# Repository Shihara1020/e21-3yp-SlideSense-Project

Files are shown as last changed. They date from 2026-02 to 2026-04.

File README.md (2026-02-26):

<p align="center">
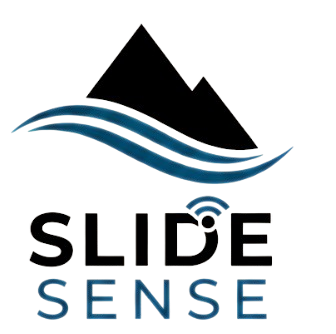
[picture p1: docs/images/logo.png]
  
</p>

<p align="center">
  
</p>

<p align="center">
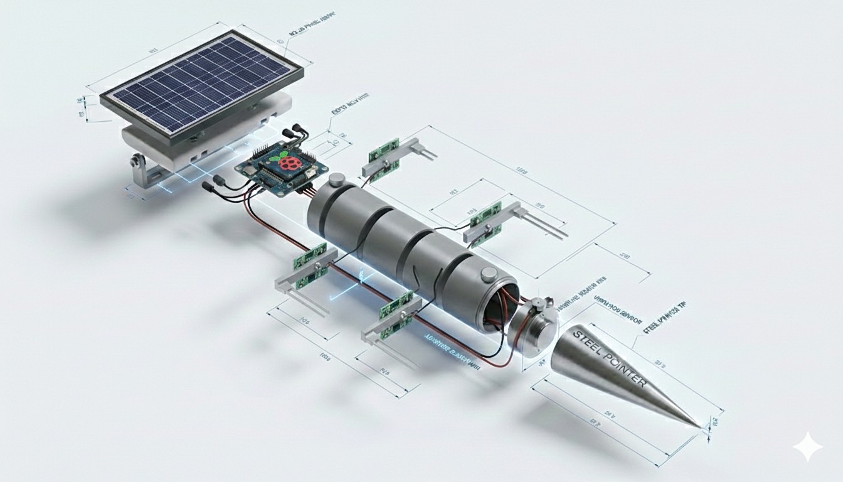
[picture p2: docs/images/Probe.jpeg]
  
</p>






## Team
- E/21/087, Shihara Dewagedara, [e21087@eng.pdn.ac.lk](mailto:e21087@eng.pdn.ac.lk)
- E/21/138, Fikry M.N.M., [e21138@eng.pdn.ac.lk](mailto:e21138@eng.pdn.ac.lk)
- E/21/302, Sahandi Perera, [e21302@eng.pdn.ac.lk](mailto:e21302@eng.pdn.ac.lk)
- E/21/452, Zaid M.R.M., [e21452@eng.pdn.ac.lk](mailto:e21452@eng.pdn.ac.lk)

#### Table of Contents

1. [Introduction](#introduction)
2. [Overall System Architecture](#overall-system-architecture)
3. [Data Flow Architecture](#data-flow-architecture)
4. [Software Architecture & Stack](#software-architecture--stack)
5. [Project Timeline](#project-timeline)
6. [Detailed Budget](#detailed-budget)
7. [Conclusion & Future Work](#conclusion--future-work)
8. [Links](#links)

## Introduction

Landslides remain a significant threat in hilly regions of Sri Lanka, often triggered by intense monsoon rainfall. **SlideSense** is an integrated IoT solution designed for real-time monitoring of high-risk slopes. 

The system moves beyond simple data logging by incorporating:
- **Redundant Communication:** Utilizing both Cloud (AWS/Firebase) and Local (Gateway) paths.
- **Edge Intelligence:** Real-time threshold analysis on the ESP32 to trigger immediate local sirens.
- **Resilience:** Designed to function even when external cellular networks fail during heavy storms.

## Overall System Architecture

SlideSense follows a **multi-layer IoT architecture**:

- **Perception Layer:** Distributed sensor nodes (ESP32) collect soil moisture, volumetric water content, and tilt data.
- **Network Layer:** Data is transmitted via MQTT protocol to a central Raspberry Pi gateway and subsequently to the AWS IoT Core.
- **Application Layer:** A React-based web dashboard and Firebase Cloud Messaging (FCM) provide localized alerts and historical data visualization for authorities.

## Data Flow Architecture

The system ensures reliable and redundant data transmission:

1. Sensors collect environmental data  
2. ESP32 performs edge analysis  
3. Data transmitted via LoRa / SIM900A  
4. Cloud (AWS/Firebase) processes & stores data  
5. Alerts triggered via Dashboard / SMS / FCM  

<p align="center">
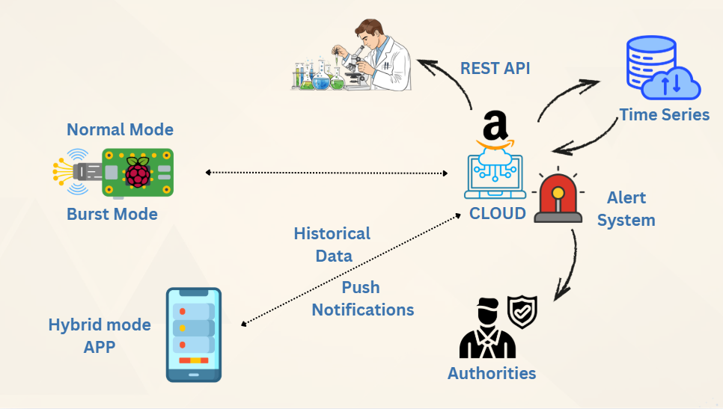
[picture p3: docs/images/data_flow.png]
  
</p>

##  Core Components

- **ESP32 WROOM 32U**
- **Capacitive Soil Moisture Sensors (x4)**
- **Tipping Bucket Rain Gauge**
- **High Sensitivity Microphone Sensor**
- **LoRa RA-02 SX1278 Module**
- **SIM900A GSM Module**
- **20W Solar Panel**
- **MPPT Charge Controller**
- **3.7V Li-Po Battery**

## ⚡ Power System

- MPPT Solar Charging
- 3.3V Regulation
- Deep Sleep Power Optimization

## Software Architecture & Stack

## 🧠 Firmware
- Arduino Framework
- FreeRTOS Task Management
- MQTT Communication
- Deep Sleep Mode

## ☁️ Backend & Cloud
- AWS IoT Core / Firebase
- Mosquitto MQTT Broker
- Node.js Gateway (Optional)
- Firebase Cloud Messaging (Alerts)

## 🖥 Frontend
- React.js Dashboard
- Real-time Data Visualization
- Alert Monitoring Panel

## 🛠 Software Stack Diagram

<p align="center">
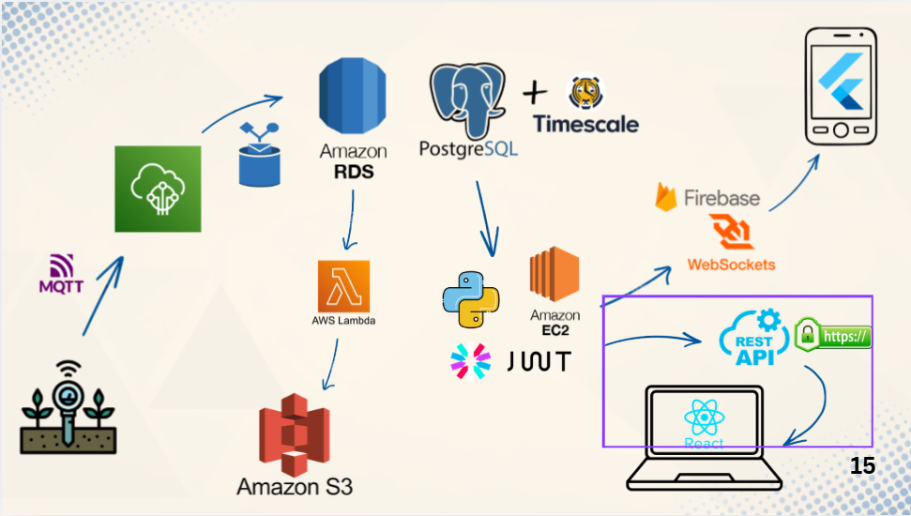
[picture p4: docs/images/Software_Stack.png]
  
</p>

##  Project Timeline

The project was executed in four structured milestones:

- Milestone 01 – Proposal & Planning  
- Milestone 02 – Hardware Setup & Testing  
- Milestone 03 – Working Prototype  
- Milestone 04 – Final Product & Documentation  

<p align="center">
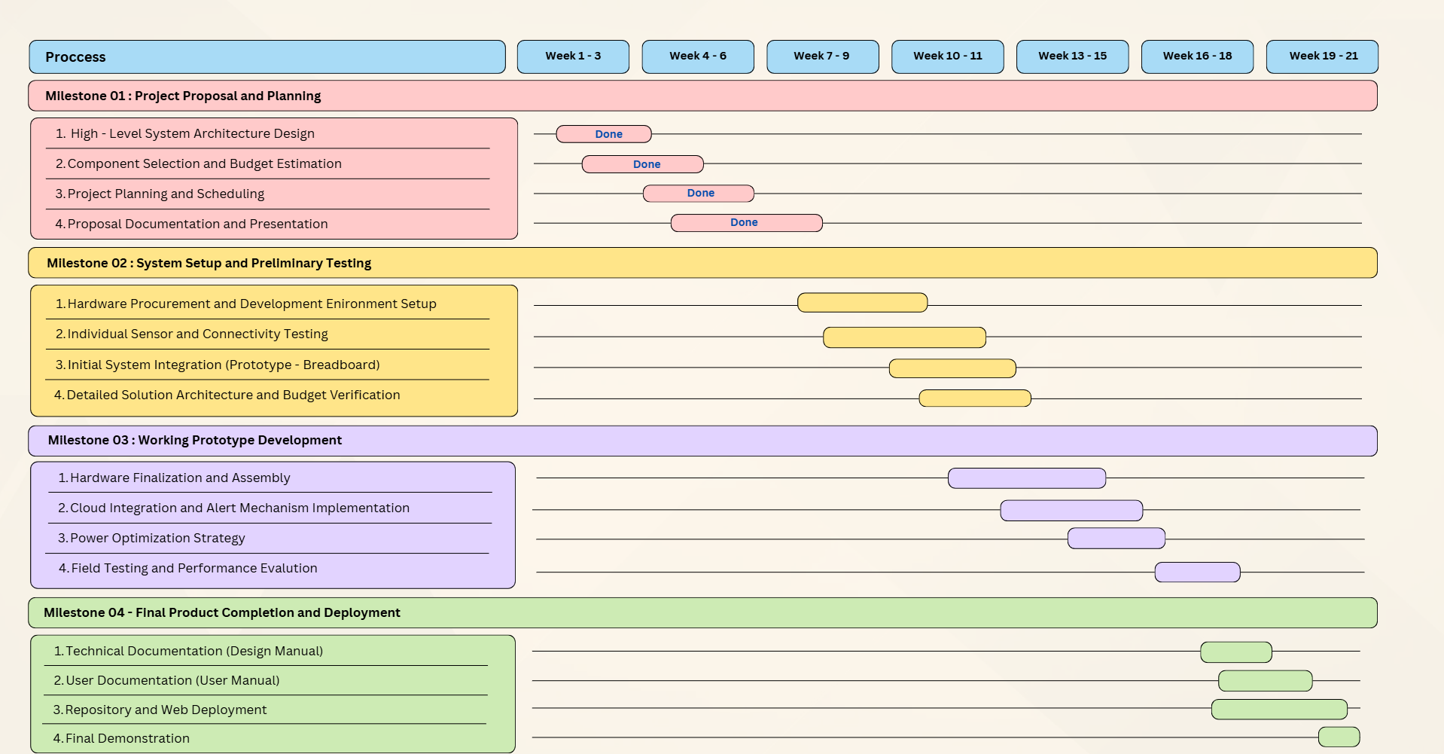
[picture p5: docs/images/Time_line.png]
  
</p>

## Detailed Budget

| Item | Quantity | Unit Cost (LKR) | Total (LKR) |
| :--- | :---: | :---: | :---: |
| 20W Solar Panel | 1 | 3,350 | 3,350 |
| Li-Po Battery | 1 | 1,185 | 1,185 |
| MPPT Controller | 1 | 1,450 | 1,450 |
| Voltage Regulator | 1 | 120 | 120 |
| ESP32 | 1 | 1,860 | 1,860 |
| Soil Moisture Sensor | 4 | 290 | 1,160 |
| Tipping Bucket | 1 | 4,000 | 4,000 |
| LoRa Module | 1 | 1,500 | 1,500 |
| Microphone Sensor | 1 | 200 | 200 |
| SIM900A | 1 | 1,450 | 1,450 |
| **Total Cost** |  |  | **16,275 LKR** |

## Conclusion & Future Work

SlideSense demonstrates a **cost-effective, scalable, and resilient landslide monitoring system** integrating edge intelligence with cloud-based alerts.

### Future Enhancements
- LoRaWAN integration for extended mountainous coverage  
- Machine Learning (LSTM-based rainfall prediction)  
- IP67-rated rugged enclosure  
- Mobile application for public warning

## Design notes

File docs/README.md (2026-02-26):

---
layout: home
permalink: index.html
repository-name: e21-3yp-SlideSense
title: SlideSense
---

<p align="center">
  
</p>

<p align="center">
  
</p>

<p align="center">
  
</p>

## Team
- E/21/087, Shihara Dewagedara, [e21087@eng.pdn.ac.lk](mailto:e21087@eng.pdn.ac.lk)
- E/21/138, Fikry M.N.M., [e21138@eng.pdn.ac.lk](mailto:e21138@eng.pdn.ac.lk)
- E/21/302, Sahandi Perera, [e21302@eng.pdn.ac.lk](mailto:e21302@eng.pdn.ac.lk)
- E/21/452, Zaid M.R.M., [e21452@eng.pdn.ac.lk](mailto:e21452@eng.pdn.ac.lk)

#### Table of Contents

1. [Introduction](#introduction)
2. [Overall System Architecture](#overall-system-architecture)
3. [Data Flow Architecture](#data-flow-architecture)
4. [Hardware Design](#hardware-design)
5. [Software Architecture & Stack](#software-architecture--stack)
6. [Project Timeline](#project-timeline)
7. [Testing & Validation](#testing--validation)
8. [Detailed Budget](#detailed-budget)
9. [Conclusion & Future Work](#conclusion--future-work)
10. [Links](#links)

## Introduction

Landslides remain a significant threat in hilly regions of Sri Lanka, often triggered by intense monsoon rainfall. **SlideSense** is an integrated IoT solution designed for real-time monitoring of high-risk slopes. 

The system moves beyond simple data logging by incorporating:
- **Redundant Communication:** Utilizing both Cloud (AWS/Firebase) and Local (Gateway) paths.
- **Edge Intelligence:** Real-time threshold analysis on the ESP32 to trigger immediate local sirens.
- **Resilience:** Designed to function even when external cellular networks fail during heavy storms.

## Overall System Architecture

SlideSense follows a **multi-layer IoT architecture**:

- **Perception Layer:** Distributed sensor nodes (ESP32) collect soil moisture, volumetric water content, and tilt data.
- **Network Layer:** Data is transmitted via MQTT protocol to a central Raspberry Pi gateway and subsequently to the AWS IoT Core.
- **Application Layer:** A React-based web dashboard and Firebase Cloud Messaging (FCM) provide localized alerts and historical data visualization for authorities.

<p align="center">
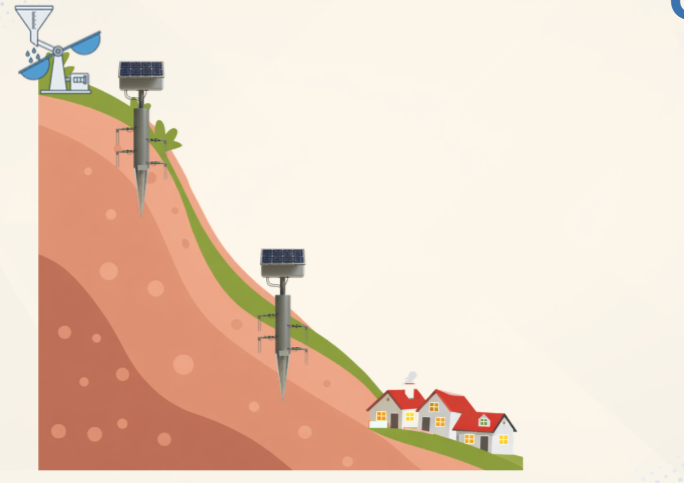
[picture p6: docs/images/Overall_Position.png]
  
</p>

## Data Flow Architecture

The system ensures reliable and redundant data transmission:

1. Sensors collect environmental data  
2. ESP32 performs edge analysis  
3. Data transmitted via LoRa / SIM900A  
4. Cloud (AWS/Firebase) processes & stores data  
5. Alerts triggered via Dashboard / SMS / FCM  

<p align="center">
  
</p>

##  Core Components

- **ESP32 WROOM 32U**
- **Capacitive Soil Moisture Sensors (x4)**
- **Tipping Bucket Rain Gauge**
- **High Sensitivity Microphone Sensor**
- **LoRa RA-02 SX1278 Module**
- **SIM900A GSM Module**
- **20W Solar Panel**
- **MPPT Charge Controller**
- **3.7V Li-Po Battery**

##  Power System

- MPPT Solar Charging
- 3.3V Regulation
- Deep Sleep Power Optimization

## Software Architecture & Stack

## Firmware
- Arduino Framework
- FreeRTOS Task Management
- MQTT Communication
- Deep Sleep Mode

##  Backend & Cloud
- AWS IoT Core / Firebase
- Mosquitto MQTT Broker
- Node.js Gateway (Optional)
- Firebase Cloud Messaging (Alerts)

##  Frontend
- React.js Dashboard
- Real-time Data Visualization
- Alert Monitoring Panel

## 🛠 Software Stack Diagram

<p align="center">
  
</p>

##  Project Timeline

The project was executed in four structured milestones:

- Milestone 01 – Proposal & Planning  
- Milestone 02 – Hardware Setup & Testing  
- Milestone 03 – Working Prototype  
- Milestone 04 – Final Product & Documentation  

<p align="center">
  
</p>

## Testing & Validation

##  Hardware Testing
- Soil moisture calibration (dry vs saturated soil)
- Rain gauge pulse verification
- Battery discharge & deep sleep measurement

##  Connectivity Testing
- MQTT latency: < 2 seconds
- GSM fallback verification
- LoRa range testing in open field

##  Failover Testing
- Local gateway broadcast when WAN disconnected
- Alert triggering under simulated rainfall conditions

## Detailed Budget

| Item | Quantity | Unit Cost (LKR) | Total (LKR) |
| :--- | :---: | :---: | :---: |
| 20W Solar Panel | 1 | 3,350 | 3,350 |
| Li-Po Battery | 1 | 1,185 | 1,185 |
| MPPT Controller | 1 | 1,450 | 1,450 |
| Voltage Regulator | 1 | 120 | 120 |
| ESP32 | 1 | 1,860 | 1,860 |
| Soil Moisture Sensor | 4 | 290 | 1,160 |
| Tipping Bucket | 1 | 4,000 | 4,000 |
| LoRa Module | 1 | 1,500 | 1,500 |
| Microphone Sensor | 1 | 200 | 200 |
| SIM900A | 1 | 1,450 | 1,450 |
| **Total Cost** |  |  | **16,275 LKR** |

## Conclusion & Future Work

SlideSense demonstrates a **cost-effective, scalable, and resilient landslide monitoring system** integrating edge intelligence with cloud-based alerts.

### Future Enhancements
- LoRaWAN integration for extended mountainous coverage  
- Machine Learning (LSTM-based rainfall prediction)  
- IP67-rated rugged enclosure  
- Mobile application for public warning  

## Links

- [Project Repository](https://github.com/cepdnaclk/{{ page.repository-name }}){:target="_blank"}
- [Project Page](https://cepdnaclk.github.io/{{ page.repository-name}}){:target="_blank"}
- [Department of Computer Engineering](http://www.ce.pdn.ac.lk/)
- [University of Peradeniya](https://eng.pdn.ac.lk/)

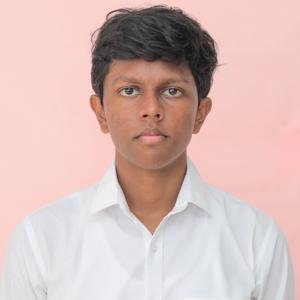
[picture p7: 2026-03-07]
docs/images/e21087.jpg

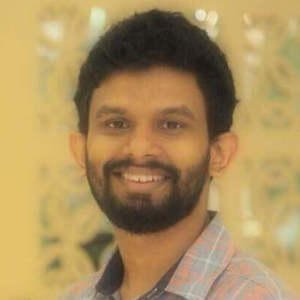
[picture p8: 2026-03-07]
docs/images/isuru-nawinne.png

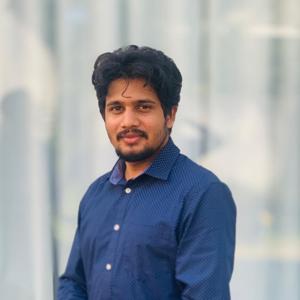
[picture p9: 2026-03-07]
docs/images/e21138.jpg

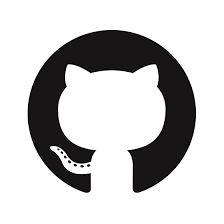
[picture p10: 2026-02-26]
docs/images/sample.png

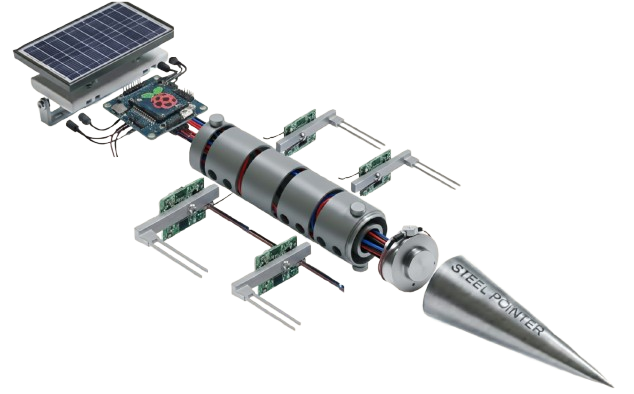
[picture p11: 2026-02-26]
docs/images/Probe.png

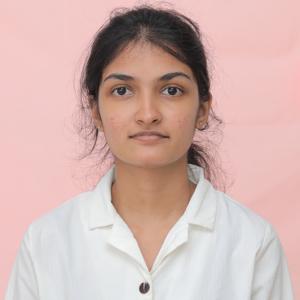
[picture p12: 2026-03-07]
docs/images/e21302.jpg

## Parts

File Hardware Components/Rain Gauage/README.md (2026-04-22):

# 🌧️ Arduino Tipping Bucket Rain Gauge

It measures rainfall by counting the number of times a bucket tips due to collected water and displays the result on an LCD screen.

The system uses a **Hall effect sensor and magnet** to detect each tip and calculates total rainfall based on calibrated values.

## ⚙️ How It Works

* Rainwater is collected through a funnel.
* Water fills one side of a **tipping bucket mechanism**.
* When the bucket reaches a certain weight, it tips.
* A **magnet attached to the bucket** passes near a Hall effect sensor.
* The Arduino detects this and increments rainfall count.
* Each tip corresponds to a fixed amount of rainfall (e.g., mm).
* The total rainfall is shown on the LCD display.

## 🧰 Components Required

* Arduino (UNO / Nano / compatible)
* Hall effect sensor
* Small magnet
* steel
* self-locking nuts
* Washers
* Flat aluminum profile
* 3-wire cable
* 3D printed parts (bucket, frame, funnel)

## 🛠️ Tools Required

* Soldering iron
* Wrenches
* 3D printer
* Computer with Arduino IDE

## 🖨️ 3D Printing

* Material: PLA (works, but PETG is recommended for outdoor use)
* Print all parts from provided `.stl` files
* Ensure proper alignment and smooth movement of the bucket

## 🔌 Circuit Connections

* Hall Sensor VCC → Arduino 5V
* Hall Sensor GND → Arduino GND
* Hall Sensor OUT → Arduino Digital Pin (e.g., D2)
* LCD SDA → A4 (UNO)
* LCD SCL → A5 (UNO)

## 📏 Calibration

Each tip equals a fixed rainfall amount. To calibrate:

1. Pour a known amount of water.
2. Count number of tips.
3. Calculate:

   ```
   calibrationFactor = total_water(mm) / number_of_tips
   ```

## Output

* Real-time rainfall displayed on LCD
* Can be extended to:

  * Store data
  * Send to cloud (IoT)
  * Trigger alerts

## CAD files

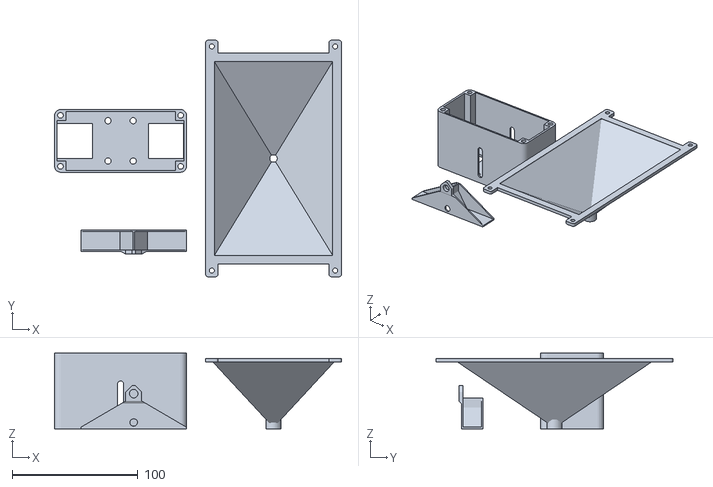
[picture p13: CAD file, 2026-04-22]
Hardware Components/Rain Gauage/Overall_Design.stl
228.0 x 188.0 x 60.0

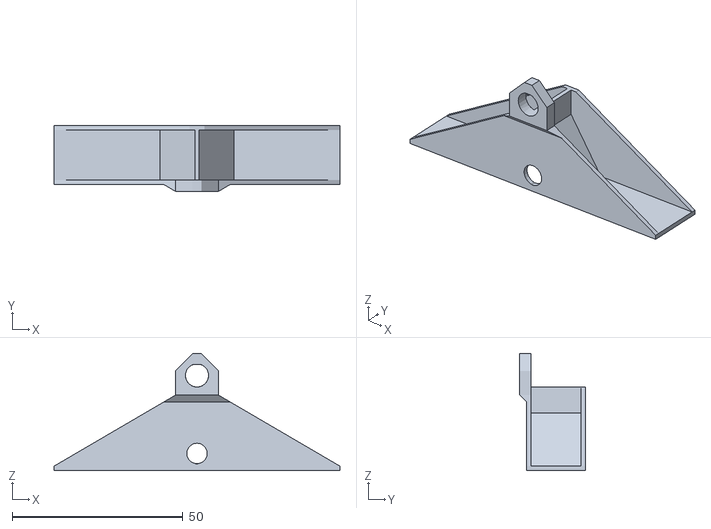
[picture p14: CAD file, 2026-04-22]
Hardware Components/Rain Gauage/Bucket.stl
83.8 x 19.2 x 34.3

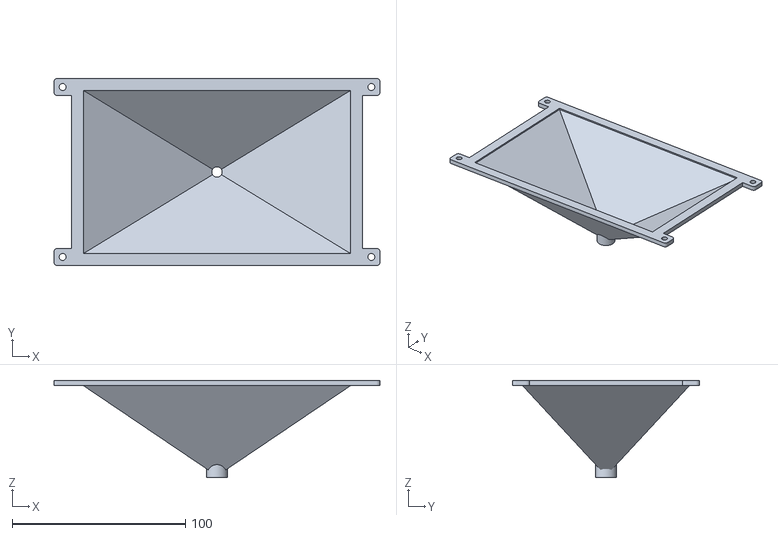
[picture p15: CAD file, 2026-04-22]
Hardware Components/Rain Gauage/Funnel.stl
188.0 x 108.0 x 56.0

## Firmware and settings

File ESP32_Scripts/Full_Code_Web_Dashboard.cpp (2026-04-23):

#include <Arduino.h>
#include <TinyGPS++.h>
#include <WiFi.h>
#include <AsyncTCP.h>
#include <ESPAsyncWebServer.h>
#include <ArduinoJson.h>

// ===== WIFI =====
const char *ssid = "";
const char *password = "";

// ===== GPS =====
HardwareSerial SerialGPS(2);
TinyGPSPlus gps;

// ===== PINS =====
#define MOISTURE1 34
#define MOISTURE2 35
#define MOISTURE3 32
#define RAIN_PIN 14

volatile int rainCount = 0;

void IRAM_ATTR rainPulse() {
  rainCount++;
}

// ===== SERVER =====
AsyncWebServer server(80);
AsyncWebSocket ws("/ws");

// ===== HTML DASHBOARD =====
const char index_html[] PROGMEM = R"rawliteral(
<!DOCTYPE html>
<html lang="en">
<head>
  <meta charset="UTF-8" />
  <meta name="viewport" content="width=device-width, initial-scale=1.0"/>
  <title>Landslide Monitor</title>

  <!-- Leaflet Map -->
  <link rel="stylesheet" href="https://unpkg.com/leaflet@1.9.4/dist/leaflet.css"/>
  <script src="https://unpkg.com/leaflet@1.9.4/dist/leaflet.js"></script>
  <!-- Chart.js -->
  <script src="https://cdn.jsdelivr.net/npm/chart.js@4.4.0/dist/chart.umd.min.js"></script>
  <!-- Google Fonts -->
  <link href="https://fonts.googleapis.com/css2?family=Share+Tech+Mono&family=Exo+2:wght@300;600;800&display=swap" rel="stylesheet"/>

  <style>
    :root {
      --bg: #060d1a;
      --surface: #0b1628;
      --card: #0f1f38;
      --border: #1a3a5c;
      --accent: #00e5ff;
      --accent2: #39ff14;
      --warn: #ff9800;
      --danger: #ff1744;
      --text: #cfe8ff;
      --muted: #4a7fa5;
      --font-mono: 'Share Tech Mono', monospace;
      --font-ui: 'Exo 2', sans-serif;
    }

    * { box-sizing: border-box; margin: 0; padding: 0; }

    body {
      background: var(--bg);
      color: var(--text);
      font-family: var(--font-ui);
      min-height: 100vh;
      overflow-x: hidden;
    }

    /* Animated grid background */
    body::before {
      content: '';
      position: fixed;
      inset: 0;
      background-image:
        linear-gradient(rgba(0,229,255,0.03) 1px, transparent 1px),
        linear-gradient(90deg, rgba(0,229,255,0.03) 1px, transparent 1px);
      background-size: 40px 40px;
      pointer-events: none;
      z-index: 0;
    }

    .container {
      position: relative;
      z-index: 1;
      max-width: 1400px;
      margin: 0 auto;
      padding: 20px;
    }

    /* ---- HEADER ---- */
    header {
      display: flex;
      align-items: center;
      justify-content: space-between;
      padding: 18px 24px;
      background: linear-gradient(135deg, #0b1628cc, #0f1f38cc);
      border: 1px solid var(--border);
      border-radius: 12px;
      margin-bottom: 20px;
      backdrop-filter: blur(12px);
    }

    .header-left {
      display: flex;
      align-items: center;
      gap: 14px;
    }

    .logo-icon {
      width: 44px; height: 44px;
      background: linear-gradient(135deg, var(--accent), #0066ff);
      border-radius: 10px;
      display: flex; align-items: center; justify-content: center;
      font-size: 22px;
      box-shadow: 0 0 20px rgba(0,229,255,0.4);
    }

    header h1 {
      font-size: 1.4rem;
      font-weight: 800;
      letter-spacing: 1px;
      background: linear-gradient(90deg, var(--accent), #80dfff);
      -webkit-background-clip: text;
      -webkit-text-fill-color: transparent;
      background-clip: text;
    }

    header p {
      font-size: 0.75rem;
      color: var(--muted);
      font-family: var(--font-mono);
    }

    .status-badge {
      display: flex;
      align-items: center;
      gap: 8px;
      font-family: var(--font-mono);
      font-size: 0.8rem;
      color: var(--accent2);
      background: rgba(57,255,20,0.08);
      border: 1px solid rgba(57,255,20,0.25);
      padding: 8px 16px;
      border-radius: 20px;
    }

    .pulse-dot {
      width: 8px; height: 8px;
      background: var(--accent2);
      border-radius: 50%;
      animation: pulse 1.5s ease-in-out infinite;
      box-shadow: 0 0 8px var(--accent2);
    }

    @keyframes pulse {
      0%, 100% { opacity: 1; transform: scale(1); }
      50% { opacity: 0.4; transform: scale(0.8); }
    }

    /* ---- ALERT BANNER ---- */
    #alertBanner {
      display: none;
      background: linear-gradient(90deg, rgba(255,23,68,0.15), rgba(255,152,0,0.1));
      border: 1px solid var(--danger);
      border-radius: 10px;
      padding: 12px 20px;
      margin-bottom: 20px;
      font-weight: 600;
      font-size: 0.9rem;
      color: #ff6b8a;
      animation: flashAlert 1s ease-in-out infinite;
    }

    @keyframes flashAlert {
      0%, 100% { border-color: var(--danger); }
      50% { border-color: transparent; }
    }

    /* ---- GRID ---- */
    .grid-main {
      display: grid;
      grid-template-columns: repeat(4, 1fr);
      gap: 16px;
      margin-bottom: 20px;
    }

    .grid-bottom {
      display: grid;
      grid-template-columns: 1.2fr 1fr;
      gap: 16px;
      margin-bottom: 20px;
    }

    .grid-charts {
      display: grid;
      grid-template-columns: repeat(2, 1fr);
      gap: 16px;
    }

    /* ---- CARD ---- */
    .card {
      background: var(--card);
      border: 1px solid var(--border);
      border-radius: 12px;
      padding: 20px;
      position: relative;
      overflow: hidden;
      transition: border-color 0.3s, box-shadow 0.3s;
    }

    .card::before {
      content: '';
      position: absolute;
      top: 0; left: 0; right: 0;
      height: 2px;
      background: linear-gradient(90deg, transparent, var(--accent), transparent);
      opacity: 0.5;
    }

    .card:hover {
      border-color: var(--accent);
      box-shadow: 0 0 20px rgba(0,229,255,0.1);
    }

    .card-label {
      font-size: 0.7rem;
      text-transform: uppercase;
      letter-spacing: 2px;
      color: var(--muted);
      font-family: var(--font-mono);
      margin-bottom: 8px;
    }

    .card-value {
      font-size: 2rem;
      font-weight: 800;
      color: var(--accent);
      font-family: var(--font-mono);
      line-height: 1;
    }

    .card-unit {
      font-size: 0.75rem;
      color: var(--muted);
      margin-top: 4px;
    }

    .card-icon {
      position: absolute;
      top: 16px; right: 16px;
      font-size: 1.6rem;
      opacity: 0.2;
    }

    /* Moisture bars */
    .moisture-card .card-label { margin-bottom: 14px; }

    .moisture-item {
      margin-bottom: 14px;
    }

    .moisture-header {
      display: flex;
      justify-content: space-between;
      font-size: 0.78rem;
      color: var(--muted);
      margin-bottom: 6px;
      font-family: var(--font-mono);
    }

    .moisture-val {
      color: var(--text);
      font-weight: 600;
    }

    .bar-track {
      height: 8px;
      background: rgba(255,255,255,0.05);
      border-radius: 4px;
      overflow: hidden;
    }

    .bar-fill {
      height: 100%;
      border-radius: 4px;
      transition: width 0.8s cubic-bezier(0.4,0,0.2,1), background 0.5s;
      position: relative;
    }

    .bar-fill::after {
      content: '';
      position: absolute;
      top: 0; right: 0;
      width: 4px; height: 100%;
      background: rgba(255,255,255,0.5);
      border-radius: 2px;
    }

    /* Moisture level colors */
    .level-low    { background: linear-gradient(90deg, #1a8a4a, var(--accent2)); }
    .level-mid    { background: linear-gradient(90deg, #b8600a, var(--warn)); }
    .level-high   { background: linear-gradient(90deg, #8b0000, var(--danger)); }

    /* GPS card */
    .gps-coords {
      font-family: var(--font-mono);
      font-size: 1rem;
      color: var(--accent);
      margin-bottom: 4px;
    }

    .gps-fix {
      display: inline-block;
      font-size: 0.7rem;
      padding: 3px 10px;
      border-radius: 20px;
      margin-top: 8px;
      font-family: var(--font-mono);
    }

    .fix-ok   { background: rgba(57,255,20,0.1); color: var(--accent2); border: 1px solid rgba(57,255,20,0.3); }
    .fix-none { background: rgba(255,23,68,0.1);  color: #ff6b8a; border: 1px solid rgba(255,23,68,0.3); }

    /* Rain card */
    .rain-big {
      font-family: var(--font-mono);
      font-size: 2.8rem;
      font-weight: 800;
      color: var(--accent);
    }

    /* Map */
    #map {
      height: 320px;
      border-radius: 10px;
      border: 1px solid var(--border);
    }

    /* Charts */
    .chart-wrap {
      position: relative;
      height: 200px;
    }

    /* Risk gauge */
    .risk-wrap {
      display: flex;
      flex-direction: column;
      align-items: center;
      padding: 10px 0;
    }

    .risk-label-text {
      font-size: 0.7rem;
      text-transform: uppercase;
      letter-spacing: 2px;
      color: var(--muted);
      font-family: var(--font-mono);
      margin-bottom: 12px;
    }

    .gauge-container {
      position: relative;
      width: 160px; height: 90px;
      overflow: visible;
    }

    .gauge-svg { width: 160px; height: 100px; }

    .risk-level-text {
      font-size: 1.1rem;
      font-weight: 800;
      margin-top: 8px;
      font-family: var(--font-mono);
      letter-spacing: 2px;
    }

    /* Uptime */
    .stat-row {
      display: flex;
      justify-content: space-between;
      padding: 8px 0;
      border-bottom: 1px solid rgba(255,255,255,0.04);
      font-size: 0.82rem;
    }

    .stat-row:last-child { border-bottom: none; }
    .stat-key { color: var(--muted); font-family: var(--font-mono); }
    .stat-val { color: var(--text); font-weight: 600; font-family: var(--font-mono); }

    /* Responsive */
    @media (max-width: 900px) {
      .grid-main { grid-template-columns: repeat(2, 1fr); }
      .grid-bottom { grid-template-columns: 1fr; }
      .grid-charts { grid-template-columns: 1fr; }
    }

    @media (max-width: 520px) {
      .grid-main { grid-template-columns: 1fr; }
    }

    /* Glow effects on danger */
    .danger-glow {
      box-shadow: 0 0 24px rgba(255,23,68,0.3) !important;
      border-color: var(--danger) !important;
    }

    /* Scanline overlay */
    body::after {
      content: '';
      position: fixed;
      inset: 0;
      background: repeating-linear-gradient(
        0deg,
        transparent,
        transparent 2px,
        rgba(0,0,0,0.03) 2px,
        rgba(0,0,0,0.03) 4px
      );
      pointer-events: none;
      z-index: 0;
    }

    .card-title {
      font-size: 0.85rem;
      font-weight: 600;
      color: var(--text);
      margin-bottom: 14px;
      letter-spacing: 0.5px;
    }
  </style>
</head>
<body>

<div class="container">

  <!-- HEADER -->
  <header>
    <div class="header-left">
      <div class="logo-icon">🌋</div>
      <div>
        <h1>LANDSLIDE MONITOR</h1>
        <p>ESP32 · Real-time Terrain Intelligence</p>
      </div>
    </div>
    <div class="status-badge">
      <div class="pulse-dot"></div>
      <span id="connStatus">CONNECTING…</span>
    </div>
  </header>

  <!-- ALERT BANNER -->
  <div id="alertBanner">⚠️ HIGH RISK ALERT — Moisture levels critical. Immediate inspection recommended.</div>

  <!-- STAT CARDS -->
  <div class="grid-main">

    <!-- GPS -->
    <div class="card" id="gpsCard">
      <div class="card-icon">📡</div>
      <div class="card-label">GPS Location</div>
      <div class="gps-coords" id="latVal">—</div>
      <div class="gps-coords" id="lngVal">—</div>
      <span class="gps-fix fix-none" id="gpsFix">NO FIX</span>
    </div>

    <!-- Rain -->
    <div class="card" id="rainCard">
      <div class="card-icon">🌧️</div>
      <div class="card-label">Rain Pulses</div>
      <div class="rain-big" id="rainVal">0</div>
      <div class="card-unit">tip bucket events</div>
    </div>

    <!-- Uptime + Stats -->
    <div class="card">
      <div class="card-icon">⏱️</div>
      <div class="card-label">System Status</div>
      <div class="stat-row"><span class="stat-key">UPTIME</span><span class="stat-val" id="uptimeVal">0s</span></div>
      <div class="stat-row"><span class="stat-key">PACKETS</span><span class="stat-val" id="packetVal">0</span></div>
      <div class="stat-row"><span class="stat-key">GPS SAT</span><span class="stat-val" id="satVal">—</span></div>
      <div class="stat-row"><span class="stat-key">HDOP</span><span class="stat-val" id="hdopVal">—</span></div>
    </div>

    <!-- Risk Gauge -->
    <div class="card risk-wrap">
      <div class="risk-label-text">Risk Level</div>
      <div class="gauge-container">
        <svg class="gauge-svg" viewBox="0 0 160 100">
          <!-- Track -->
          <path d="M 10 90 A 70 70 0 0 1 150 90" fill="none" stroke="#1a3a5c" stroke-width="14" stroke-linecap="round"/>
          <!-- Fill -->
          <path id="gaugeFill" d="M 10 90 A 70 70 0 0 1 150 90" fill="none" stroke="#39ff14" stroke-width="14" stroke-linecap="round"
                stroke-dasharray="220" stroke-dashoffset="220" style="transition: stroke-dashoffset 1s, stroke 0.5s;"/>
          <!-- Needle -->
          <line id="gaugeNeedle" x1="80" y1="90" x2="80" y2="28" stroke="white" stroke-width="2.5"
                stroke-linecap="round" style="transform-origin: 80px 90px; transition: transform 1s;"/>
          <circle cx="80" cy="90" r="5" fill="white"/>
          <!-- Labels -->
          <text x="6" y="106" fill="#4a7fa5" font-size="10" font-family="monospace">LOW</text>
          <text x="120" y="106" fill="#4a7fa5" font-size="10" font-family="monospace">HIGH</text>
        </svg>
      </div>
      <div class="risk-level-text" id="riskText" style="color: var(--accent2);">LOW</div>
    </div>

  </div>

  <!-- MOISTURE + MAP -->
  <div class="grid-bottom">

    <!-- Map -->
    <div class="card" style="padding: 16px;">
      <div class="card-title">📍 Live GPS Map</div>
      <div id="map"></div>
    </div>

    <!-- Moisture Sensors -->
    <div class="card moisture-card">
      <div class="card-label">Soil Moisture Sensors</div>

      <div class="moisture-item">
        <div class="moisture-header">
          <span>Sensor 1</span>
          <span class="moisture-val"><span id="m1v">0</span> / 4095</span>
        </div>
        <div class="bar-track"><div class="bar-fill level-low" id="bar1" style="width:0%"></div></div>
      </div>

      <div class="moisture-item">
        <div class="moisture-header">
          <span>Sensor 2</span>
          <span class="moisture-val"><span id="m2v">0</span> / 4095</span>
        </div>
        <div class="bar-track"><div class="bar-fill level-low" id="bar2" style="width:0%"></div></div>
      </div>

      <div class="moisture-item">
        <div class="moisture-header">
          <span>Sensor 3</span>
          <span class="moisture-val"><span id="m3v">0</span> / 4095</span>
        </div>
        <div class="bar-track"><div class="bar-fill level-low" id="bar3" style="width:0%"></div></div>
      </div>

      <div style="margin-top: 18px;">
        <div class="card-label" style="margin-bottom:8px;">Average Moisture</div>
        <div class="card-value" id="avgMoisture">0</div>
        <div class="card-unit">out of 4095 (12-bit ADC)</div>
      </div>
    </div>

  </div>

  <!-- CHARTS -->
  <div class="grid-charts">

    <div class="card">
      <div class="card-title">📈 Moisture History (last 30s)</div>
      <div class="chart-wrap">
        <canvas id="moistureChart"></canvas>
      </div>
    </div>

    <div class="card">
      <div class="card-title">🌧️ Rain Accumulation</div>
      <div class="chart-wrap">
        <canvas id="rainChart"></canvas>
      </div>
    </div>

  </div>

</div><!-- /container -->

<script>
// ============================================================
//  STATE
// ============================================================
let packets = 0;
let startTime = Date.now();
let map, marker, circle;
let lastLat = 0, lastLng = 0;

// History buffers (30 points)
const MAX_HIST = 30;
const labels    = [];
const hist_m1   = [], hist_m2 = [], hist_m3 = [];
const hist_rain = [];
const hist_time = [];

// ============================================================
//  LEAFLET MAP
// ============================================================
map = L.map('map', {
  center: [7.2, 80.7],   // Sri Lanka default
  zoom: 10,
  zoomControl: true
});

L.tileLayer('https://{s}.tile.openstreetmap.org/{z}/{x}/{y}.png', {
  attribution: '© OpenStreetMap',
  maxZoom: 19
}).addTo(map);

const customIcon = L.divIcon({
  html: '<div style="font-size:22px; filter: drop-shadow(0 0 6px #00e5ff);">📍</div>',
  iconSize: [30, 30],
  iconAnchor: [15, 30],
  className: ''
});

// ============================================================
//  CHART.JS — MOISTURE
// ============================================================
const mCtx = document.getElementById('moistureChart').getContext('2d');
const moistureChart = new Chart(mCtx, {
  type: 'line',
  data: {
    labels: labels,
    datasets: [
      {
        label: 'Sensor 1',
        data: hist_m1,
        borderColor: '#00e5ff',
        backgroundColor: 'rgba(0,229,255,0.06)',
        borderWidth: 2,
        pointRadius: 0,
        tension: 0.4,
        fill: true
      },
      {
        label: 'Sensor 2',
        data: hist_m2,
        borderColor: '#39ff14',
        backgroundColor: 'rgba(57,255,20,0.05)',
        borderWidth: 2,
        pointRadius: 0,
        tension: 0.4,
        fill: true
      },
      {
        label: 'Sensor 3',
        data: hist_m3,
        borderColor: '#ff9800',
        backgroundColor: 'rgba(255,152,0,0.05)',
        borderWidth: 2,
        pointRadius: 0,
        tension: 0.4,
        fill: true
      }
    ]
  },
  options: {
    responsive: true,
    maintainAspectRatio: false,
    animation: { duration: 300 },
    scales: {
      x: { display: false },
      y: {
        min: 0, max: 4095,
        grid: { color: 'rgba(255,255,255,0.04)' },
        ticks: { color: '#4a7fa5', font: { family: 'Share Tech Mono', size: 11 } }
      }
    },
    plugins: {
      legend: {
        labels: { color: '#cfe8ff', font: { family: 'Share Tech Mono', size: 11 } }
      }
    }
  }
});

// ============================================================
//  CHART.JS — RAIN
// ============================================================
const rCtx = document.getElementById('rainChart').getContext('2d');
const rainChart = new Chart(rCtx, {
  type: 'bar',
  data: {
    labels: labels,
    datasets: [{
      label: 'Rain Pulses',
      data: hist_rain,
      backgroundColor: 'rgba(0,229,255,0.3)',
      borderColor: '#00e5ff',
      borderWidth: 1,
      borderRadius: 3
    }]
  },
  options: {
    responsive: true,
    maintainAspectRatio: false,
    animation: { duration: 300 },
    scales: {
      x: { display: false },
      y: {
        min: 0,
        grid: { color: 'rgba(255,255,255,0.04)' },
        ticks: { color: '#4a7fa5', font: { family: 'Share Tech Mono', size: 11 } }
      }
    },
    plugins: {
      legend: {
        labels: { color: '#cfe8ff', font: { family: 'Share Tech Mono', size: 11 } }
      }
    }
  }
});

// ============================================================
//  RISK GAUGE
// ============================================================
function updateGauge(riskPct) {
  // riskPct: 0–1
  const totalLen = 220;
  const offset   = totalLen - (riskPct * totalLen);

  const fill   = document.getElementById('gaugeFill');
  const needle = document.getElementById('gaugeNeedle');
  const text   = document.getElementById('riskText');

  fill.style.strokeDashoffset = offset;

  // Needle: -90deg (left=low) to +90deg (right=high)
  const deg = -90 + riskPct * 180;
  needle.style.transform = `rotate(${deg}deg)`;

  if (riskPct < 0.35) {
    fill.style.stroke = '#39ff14';
    text.textContent = 'LOW';
    text.style.color = '#39ff14';
  } else if (riskPct < 0.65) {
    fill.style.stroke = '#ff9800';
    text.textContent = 'MODERATE';
    text.style.color = '#ff9800';
  } else if (riskPct < 0.85) {
    fill.style.stroke = '#ff5722';
    text.textContent = 'HIGH';
    text.style.color = '#ff5722';
  } else {
    fill.style.stroke = '#ff1744';
    text.textContent = 'CRITICAL';
    text.style.color = '#ff1744';
  }
}

// ============================================================
//  MOISTURE BAR HELPER
// ============================================================
function updateBar(barId, value) {
  const bar = document.getElementById(barId);
  const pct = (value / 4095) * 100;
  bar.style.width = pct + '%';
  bar.className = 'bar-fill ' +
    (pct < 35 ? 'level-low' : pct < 70 ? 'level-mid' : 'level-high');
}

// ============================================================
//  UPTIME TICKER
// ============================================================
setInterval(() => {
  const sec = Math.floor((Date.now() - startTime) / 1000);
  const h = Math.floor(sec / 3600);
  const m = Math.floor((sec % 3600) / 60);
  const s = sec % 60;
  document.getElementById('uptimeVal').textContent =
    (h ? h + 'h ' : '') + (m ? m + 'm ' : '') + s + 's';
}, 1000);
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
void loop() {
  ws.cleanupClients();

  while (SerialGPS.available()) {
    gps.encode(SerialGPS.read());
  }

  if (millis() - lastSend > 1000) {
    notifyClients();
    lastSend = millis();
  }
}

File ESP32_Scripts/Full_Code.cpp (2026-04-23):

#include <Arduino.h>
#include <TinyGPS++.h>

HardwareSerial SerialGPS(2);
TinyGPSPlus gps;

// ===== PINS =====
#define MOISTURE1 34
#define MOISTURE2 35
#define MOISTURE3 32
#define RAIN_PIN 27

// Rain counter
volatile int rainCount = 0;

// Interrupt for rain gauge
void IRAM_ATTR rainPulse() {
  rainCount++;
}

void setup() {
  Serial.begin(9600);

  // GPS
  SerialGPS.begin(9600);

  // Moisture pins
  pinMode(MOISTURE1, INPUT);
  pinMode(MOISTURE2, INPUT);
  pinMode(MOISTURE3, INPUT);

  // Rain gauge
  pinMode(RAIN_PIN, INPUT_PULLUP);
  attachInterrupt(digitalPinToInterrupt(RAIN_PIN), rainPulse, FALLING);

  Serial.println("System Started...");
}

void loop() {

  // ===== GPS READ =====
  while (SerialGPS.available()) {
    gps.encode(SerialGPS.read());
  }

  float lat = 0.0, lng = 0.0;

  if (gps.location.isValid()) {
    lat = gps.location.lat();
    lng = gps.location.lng();
  }

  // ===== MOISTURE READ =====
  int m1 = analogRead(MOISTURE1);
  int m2 = analogRead(MOISTURE2);
  int m3 = analogRead(MOISTURE3);

  // ===== RAIN VALUE =====
  int rain = rainCount;

  // ===== PRINT DATA =====
  Serial.println("====== SENSOR DATA ======");

  Serial.print("GPS Lat: ");
  Serial.println(lat, 6);

  Serial.print("GPS Lng: ");
  Serial.println(lng, 6);

  Serial.print("Moisture 1: ");
  Serial.println(m1);

  Serial.print("Moisture 2: ");
  Serial.println(m2);

  Serial.print("Moisture 3: ");
  Serial.println(m3);

  Serial.print("Rain Count: ");
  Serial.println(rain);

  Serial.println("------------------------");

  delay(2000);
}

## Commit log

2026-04-21 backend_intialized with timescale db postgresql and springboot (#8)
2026-04-22 Add README for Arduino Tipping Bucket Rain Gauge
    Added detailed information about the Arduino Tipping Bucket Rain Gauge, including how it works, required components, tools, circuit connections, calibration, and output features.
2026-04-22 Add sample code for rain gauge using ESP32
2026-04-22 Add Hall Effect Sensor connection to AWS IoT
    This file connects an ESP32 to AWS IoT using MQTT to send tipping sensor data.
2026-04-22 Add sample code for Hall Effect sensor on ESP32
    Implement Hall Effect sensor functionality with LED indication.
2026-04-22 Add soil moisture sensor code for ESP32
2026-04-22 Add GPS module code for reading location data
    This code initializes a GPS module and prints latitude and longitude to the Serial Monitor. It also checks for GPS connectivity and alerts if no data is received.
2026-04-23 Simplify Hall Effect Sensor sample code
    Refactor code to use a single sensor pin and remove unused variables.
2026-04-23 Add full code for ESP32 sensor data collection
2026-04-23 Add full web dashboard for landslide monitoring
    This commit adds a complete web dashboard for monitoring landslide risk, integrating GPS, moisture sensors, and rain detection. It includes HTML, CSS, JavaScript for real-time data visualization and 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

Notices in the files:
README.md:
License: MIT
